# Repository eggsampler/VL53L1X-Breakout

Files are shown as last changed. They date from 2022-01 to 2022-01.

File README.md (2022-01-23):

# VL53L1X-Breakout

Minimal VL53L1X / VL53L1CX Breakout PCB developed in KiCad v6.

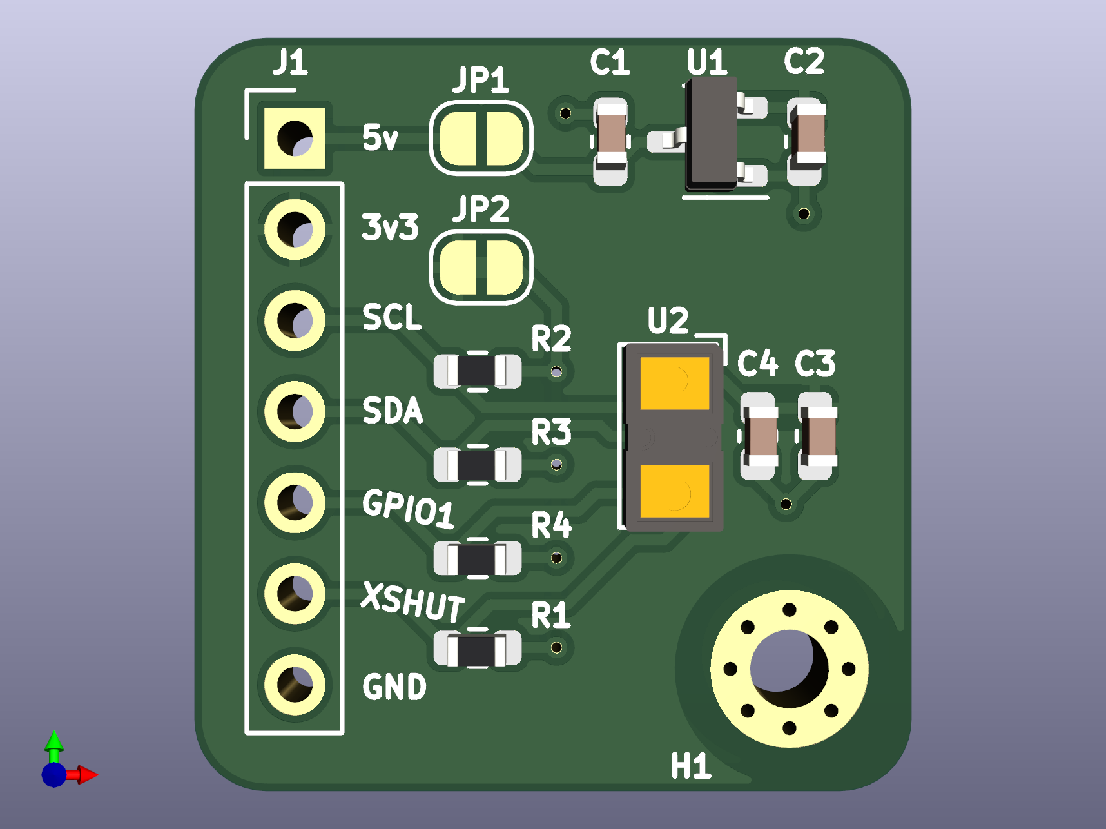
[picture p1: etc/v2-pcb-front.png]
PCB Front


Images and schematic available in `etc` folder.

Manufacturing output files available in `outputs` folder. Generated with [KiKit](https://github.com/yaqwsx/KiKit) using:

`kikit fab jlcpcb --nametemplate VL53L1CX-Breakout-v2-{} --drc --assembly --schematic VL53L1CX-Breakout.kicad_sch --ignore J1 --field LCSC --corrections JLCPCB_CORRECTION VL53L1CX-Breakout.kicad_pcb outputs`

Approximate cost from JLCPCB for 5 assembled boards is $59 AUD excluding shipping.

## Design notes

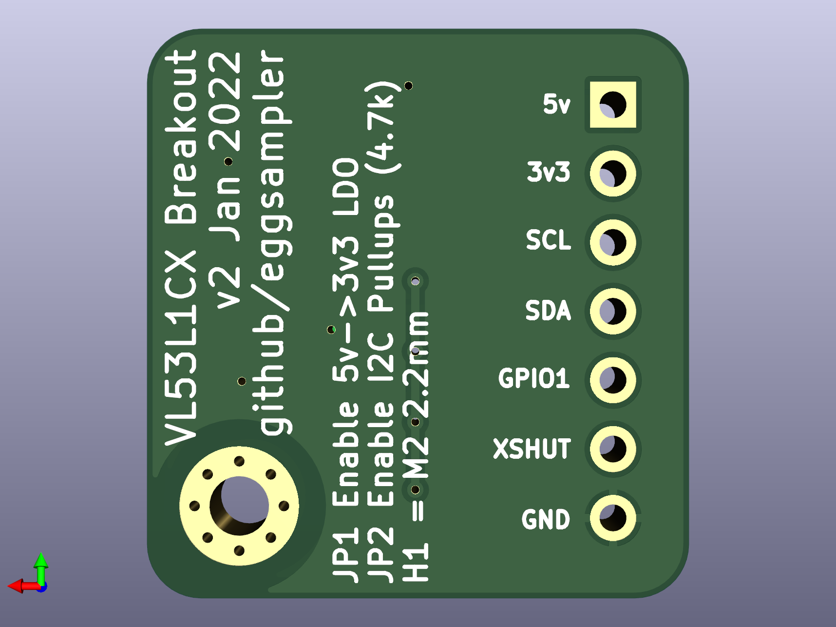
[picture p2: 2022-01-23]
etc/v2-pcb-back.png

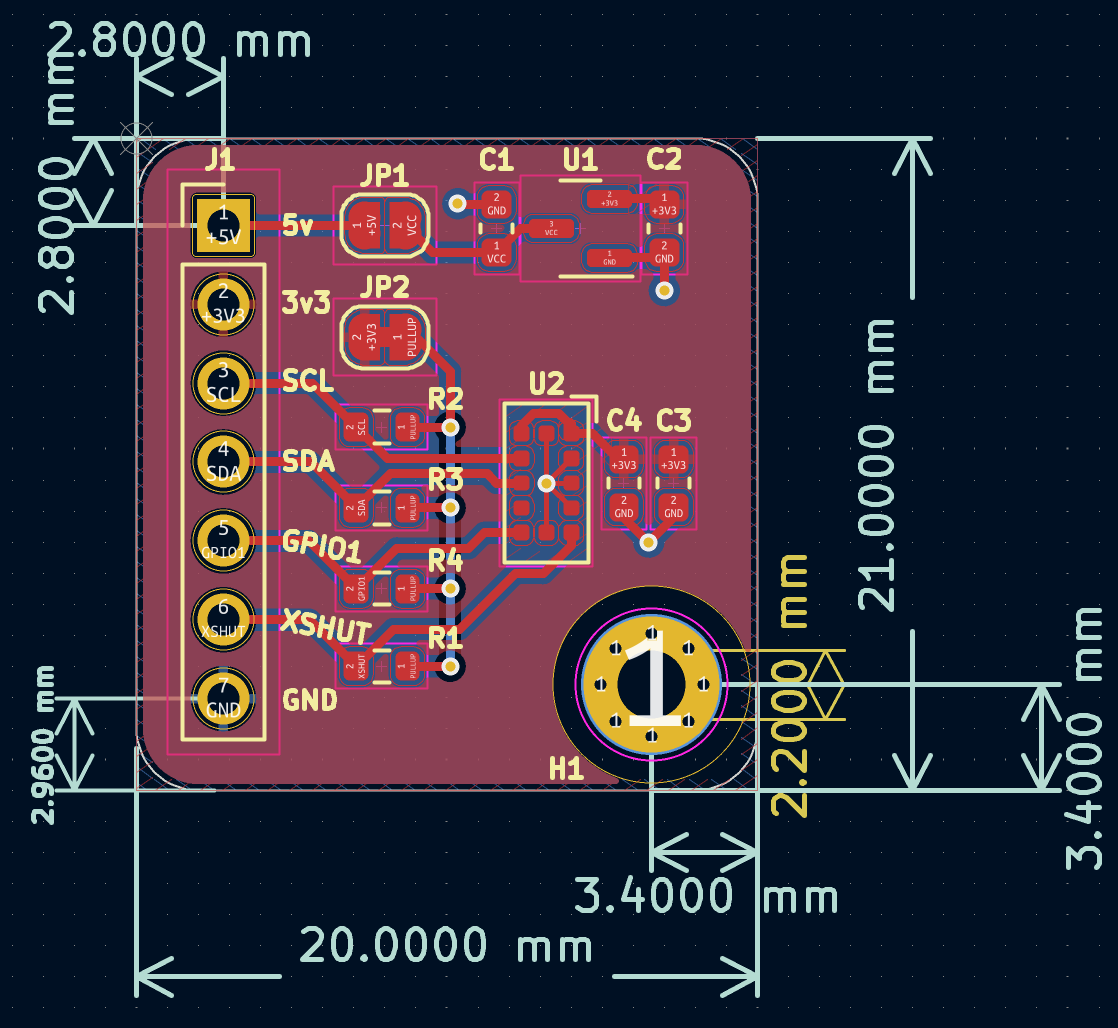
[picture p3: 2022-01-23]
etc/v2-routing.png

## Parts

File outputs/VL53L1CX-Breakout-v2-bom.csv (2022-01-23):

Comment | Designator | Footprint | LCSC
1u | C1,C2 | Capacitor_SMD:C_0603_1608Metric | C15849
100n | C3 | Capacitor_SMD:C_0603_1608Metric | C14663
4.7u | C4 | Capacitor_SMD:C_0603_1608Metric | C19666
4.7K | R1,R2,R3,R4 | Resistor_SMD:R_0603_1608Metric | C23162
XC6206PxxxMR | U1 | Package_TO_SOT_SMD:SOT-23 | C5446
VL53L1CXV0FY1 | U2 | Sensor_Distance:ST_VL53L1x | C190004

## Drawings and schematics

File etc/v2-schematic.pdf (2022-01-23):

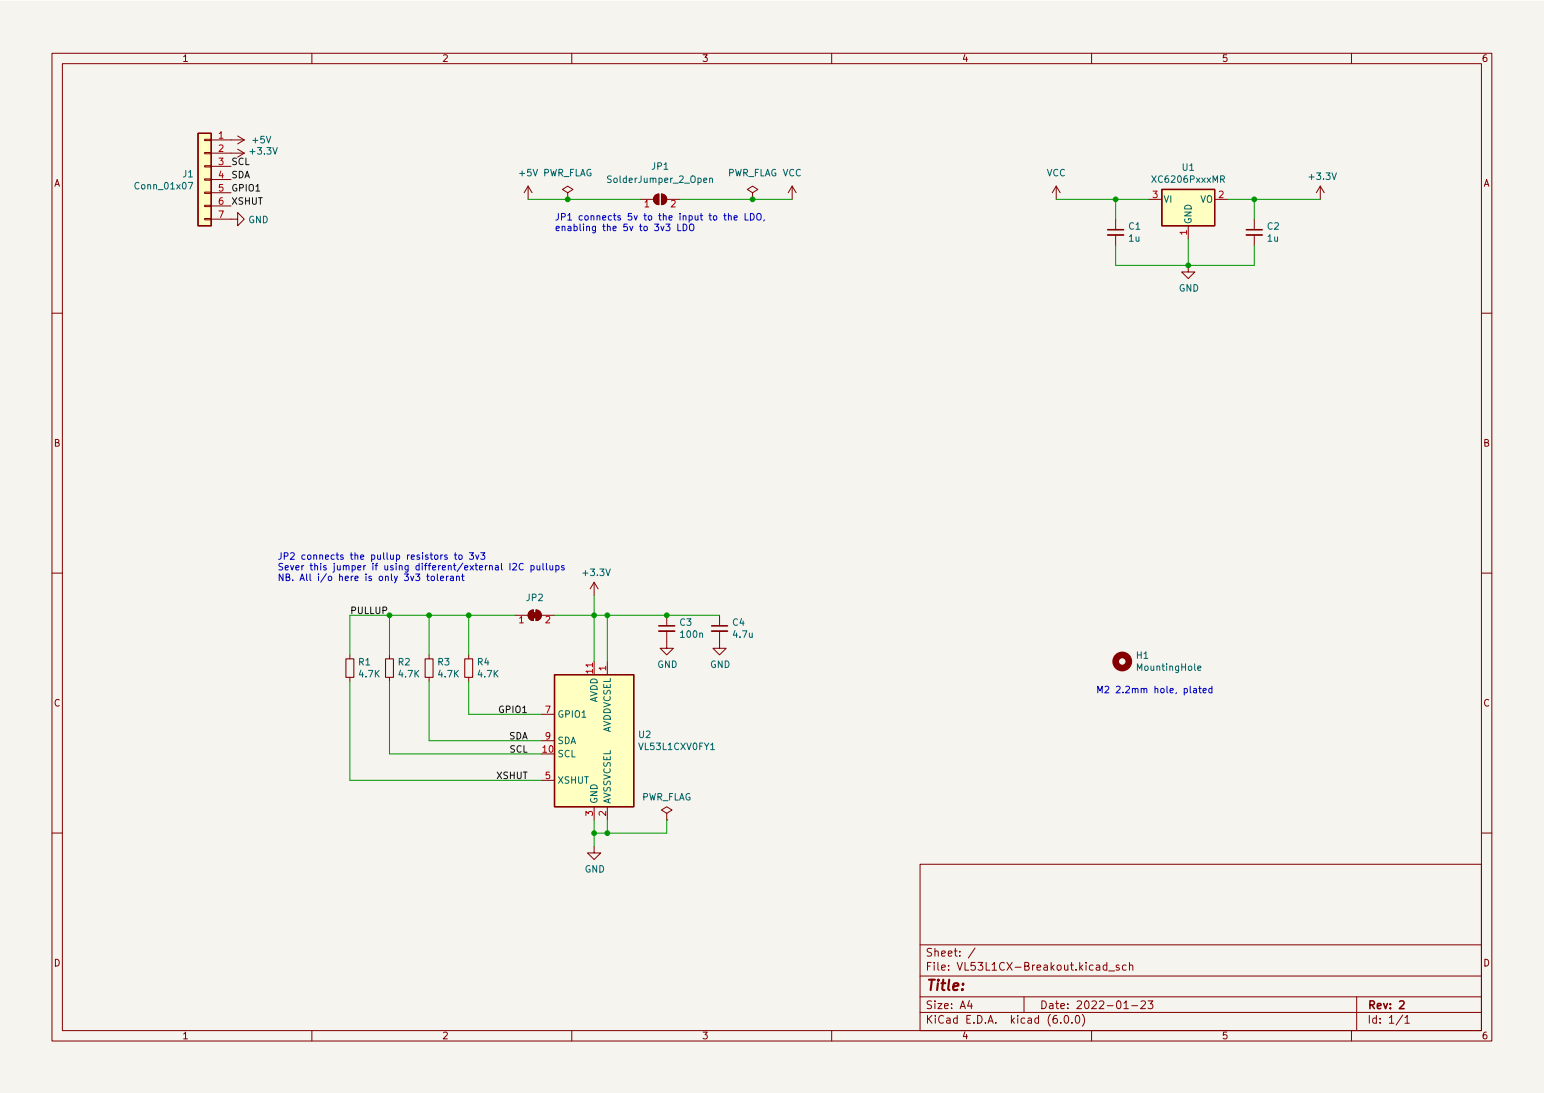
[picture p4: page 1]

JP1 connects 5v to the input to the LDO,
enabling the 5v to 3v3 LDO

JP2 connects the pullup resistors to 3v3
Sever this jumper if using different/external I2C pullups
NB. All i/o here is only 3v3 tolerant

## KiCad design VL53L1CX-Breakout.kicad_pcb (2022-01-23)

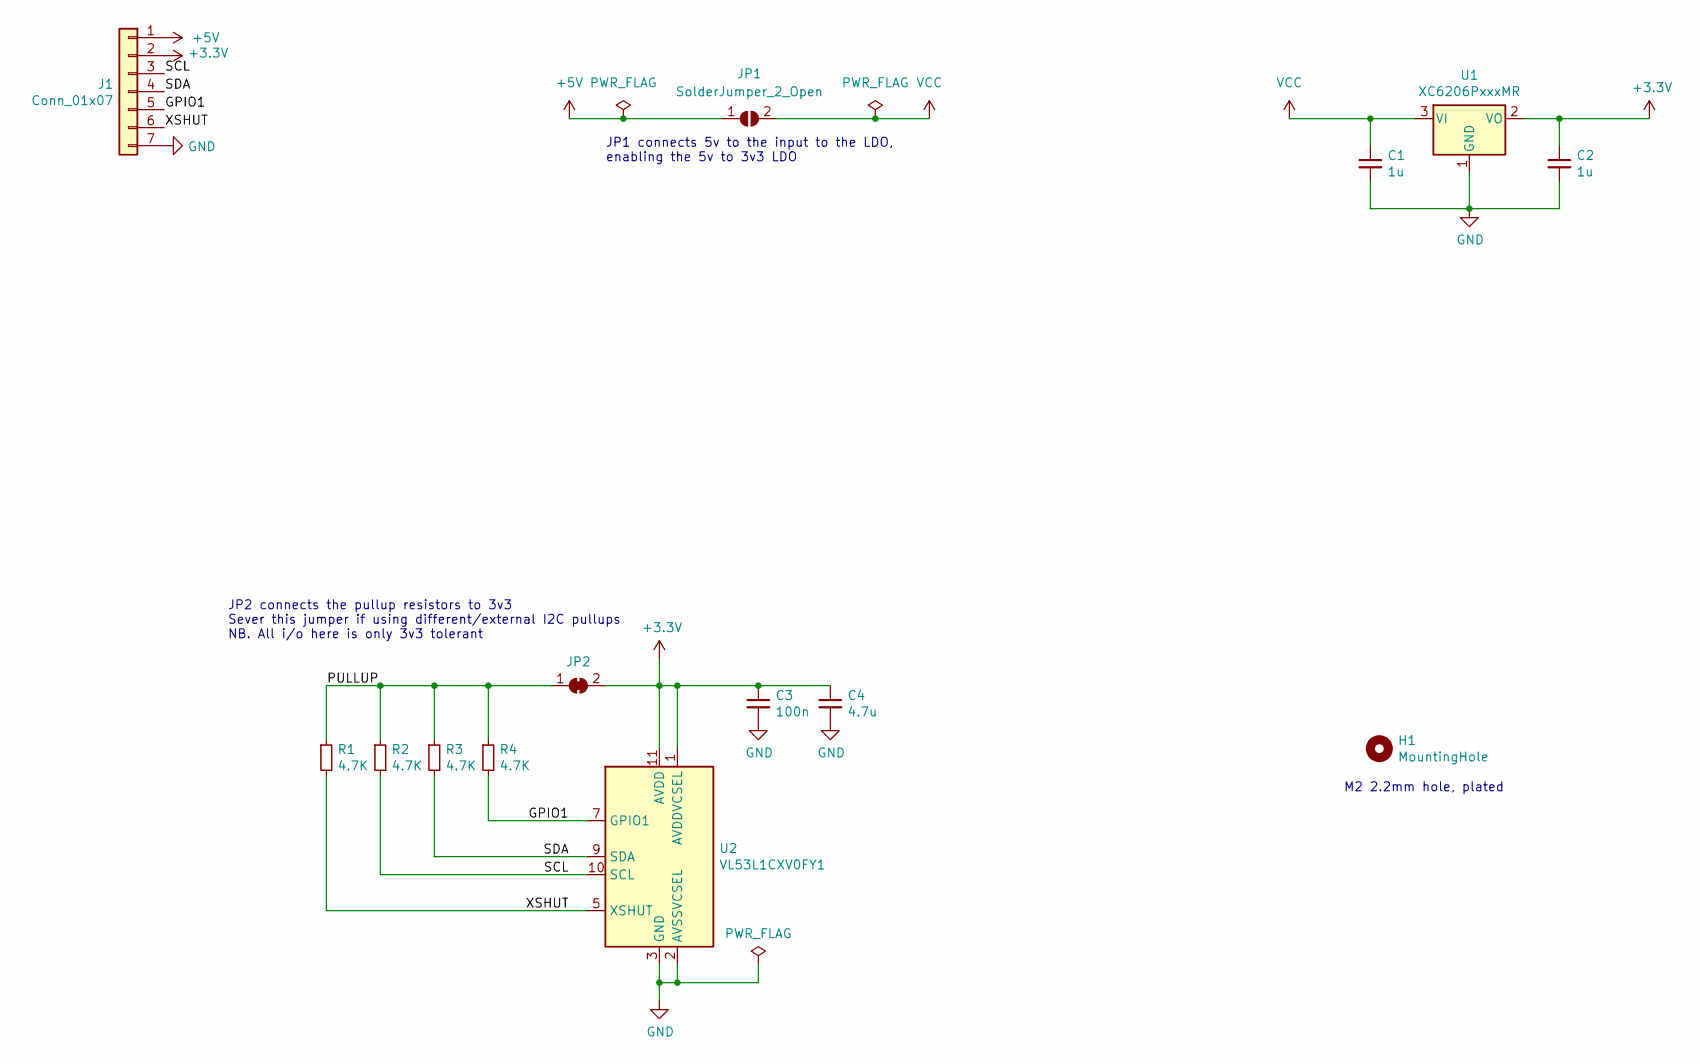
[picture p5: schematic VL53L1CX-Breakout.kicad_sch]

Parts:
C1, C2: 1u; C_0603_1608Metric; LCSC C15849
C3: 100n; C_0603_1608Metric; LCSC C14663
C4: 4.7u; C_0603_1608Metric; LCSC C19666
H1: MountingHole; MountingHole_2.2mm_M2_Pad_Via
J1: Conn_01x07; PinHeader_1x07_P2.54mm_Vertical
JP1: SolderJumper_2_Open; SolderJumper-2_P1.3mm_Open_RoundedPad1.0x1.5mm
JP2: SolderJumper_2_Bridged; SolderJumper-2_P1.3mm_Bridged_RoundedPad1.0x1.5mm
R1, R2, R3, R4: 4.7K; R_0603_1608Metric; LCSC C23162
U1: XC6206PxxxMR; SOT-23; LCSC C5446
U2: VL53L1CXV0FY1; ST_VL53L1x; LCSC C190004

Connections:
+3V3: C2.1, C3.1, C4.1, J1.2, JP2.2 (B), U1.2 (VO), U2.1 (AVDDVCSEL), U2.11 (AVDD)
+5V: J1.1, JP1.1 (A)
/GPIO1: J1.5, R4.2, U2.7 (GPIO1)
/PULLUP: JP2.1 (A), R1.1, R2.1, R3.1, R4.1
/SCL: J1.3, R2.2, U2.10 (SCL)
/SDA: J1.4, R3.2, U2.9 (SDA)
/XSHUT: J1.6, R1.2, U2.5 (XSHUT)
GND: C1.2, C2.2, C3.2, C4.2, J1.7, U1.1 (GND), U2.2 (AVSSVCSEL), U2.3 (GND), U2.4 (GND), U2.6 (GND), U2.12 (GND)
VCC: C1.1, JP1.2 (B), U1.3 (VI)

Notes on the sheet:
JP1 connects 5v to the input to the LDO, enabling the 5v to 3v3 LDO
JP2 connects the pullup resistors to 3v3 Sever this jumper if using different/external I2C pullups NB. All i/o here is only 3v3 tolerant
M2 2.2mm hole, plated

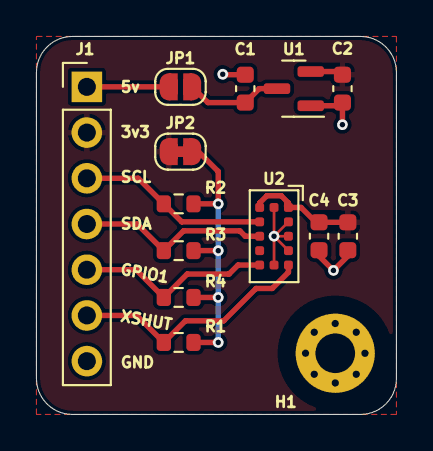
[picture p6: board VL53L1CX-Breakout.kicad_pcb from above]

Board: 2 copper layers, 20.0 x 21.0 mm, 14 parts (0 on the bottom side), 9 nets.
